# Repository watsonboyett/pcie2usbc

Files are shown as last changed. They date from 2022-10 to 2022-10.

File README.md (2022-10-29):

# PCIe to USB-C Adaptoid

A PCIe to USB-C adapter board -- plugs into a PCIe 1x card slot to breakout the data and clock lanes to a USB-C connector. 
Includes AC coupling caps and jumper resistors to aid in debugging/hacking.
Tested up to PCIe Gen 2 at 5.0 Gbps (though threre's plenty of room for improving the signal integrity).

### Schematic

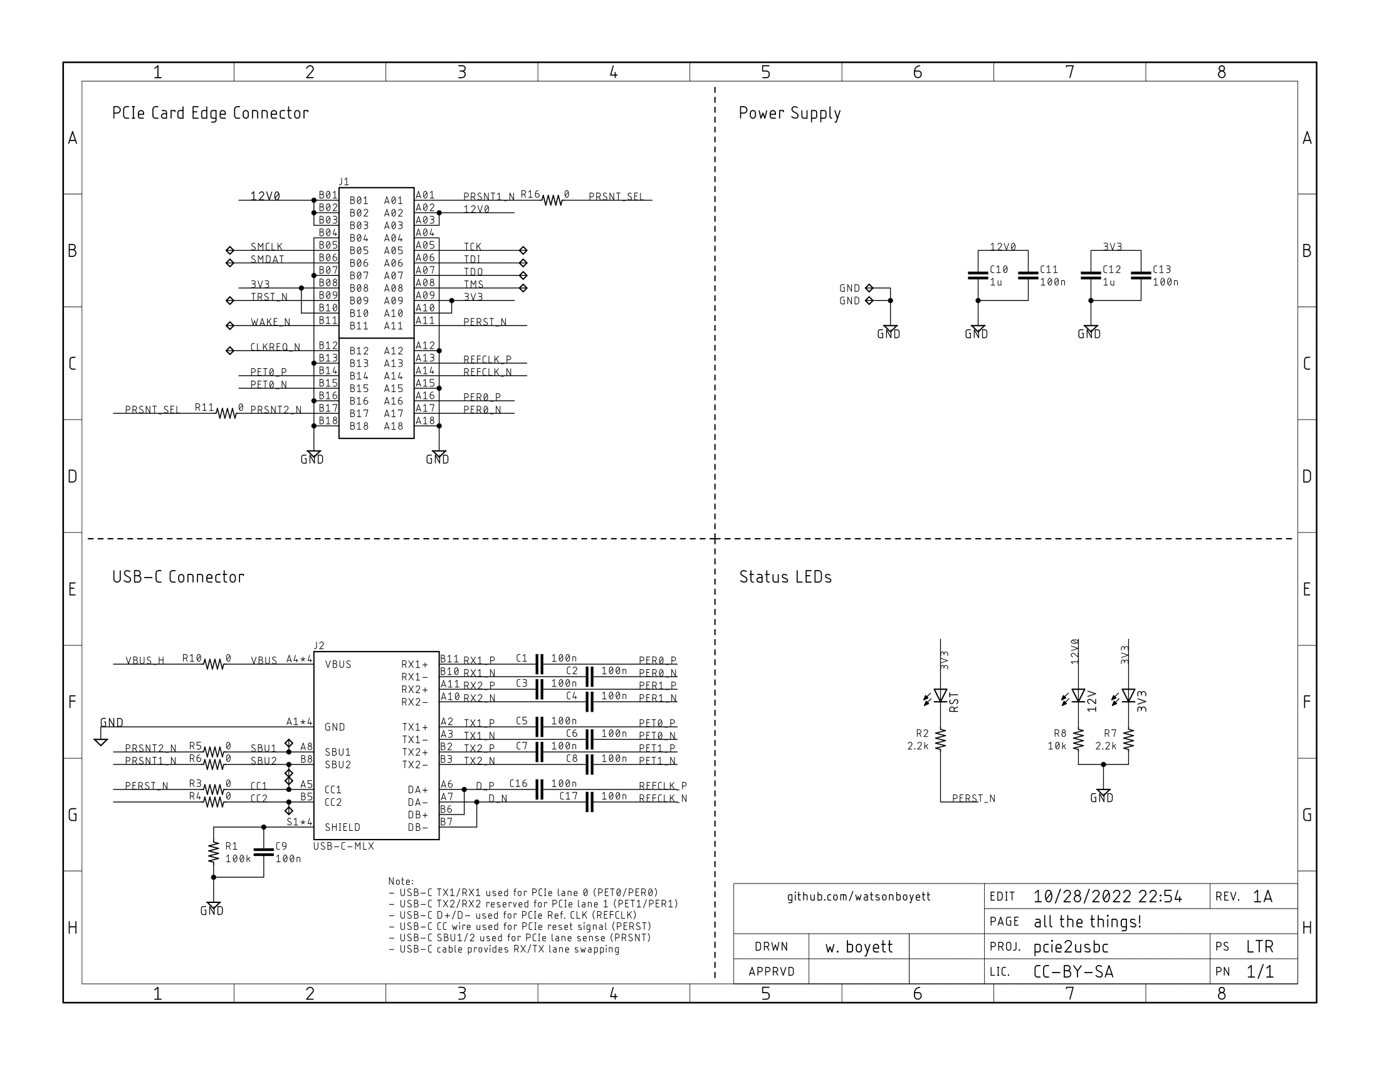
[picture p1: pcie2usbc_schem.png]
Schematic


### PCB Bottom Side

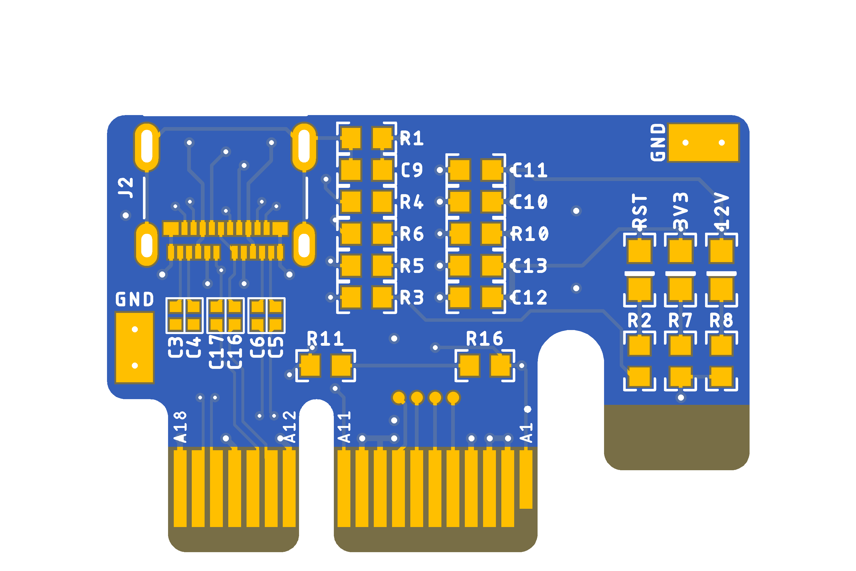
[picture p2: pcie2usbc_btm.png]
PCB Bottom Side


### PCB Top Side

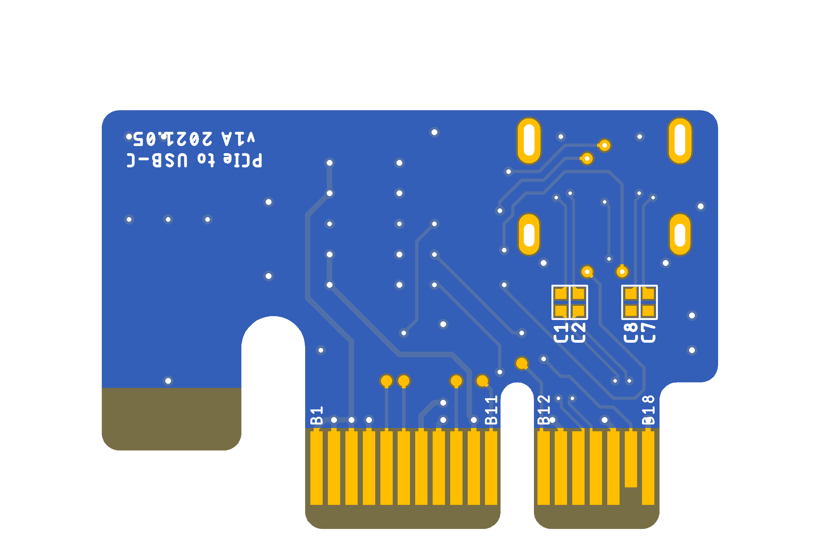
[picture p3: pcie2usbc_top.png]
PCB Top Side


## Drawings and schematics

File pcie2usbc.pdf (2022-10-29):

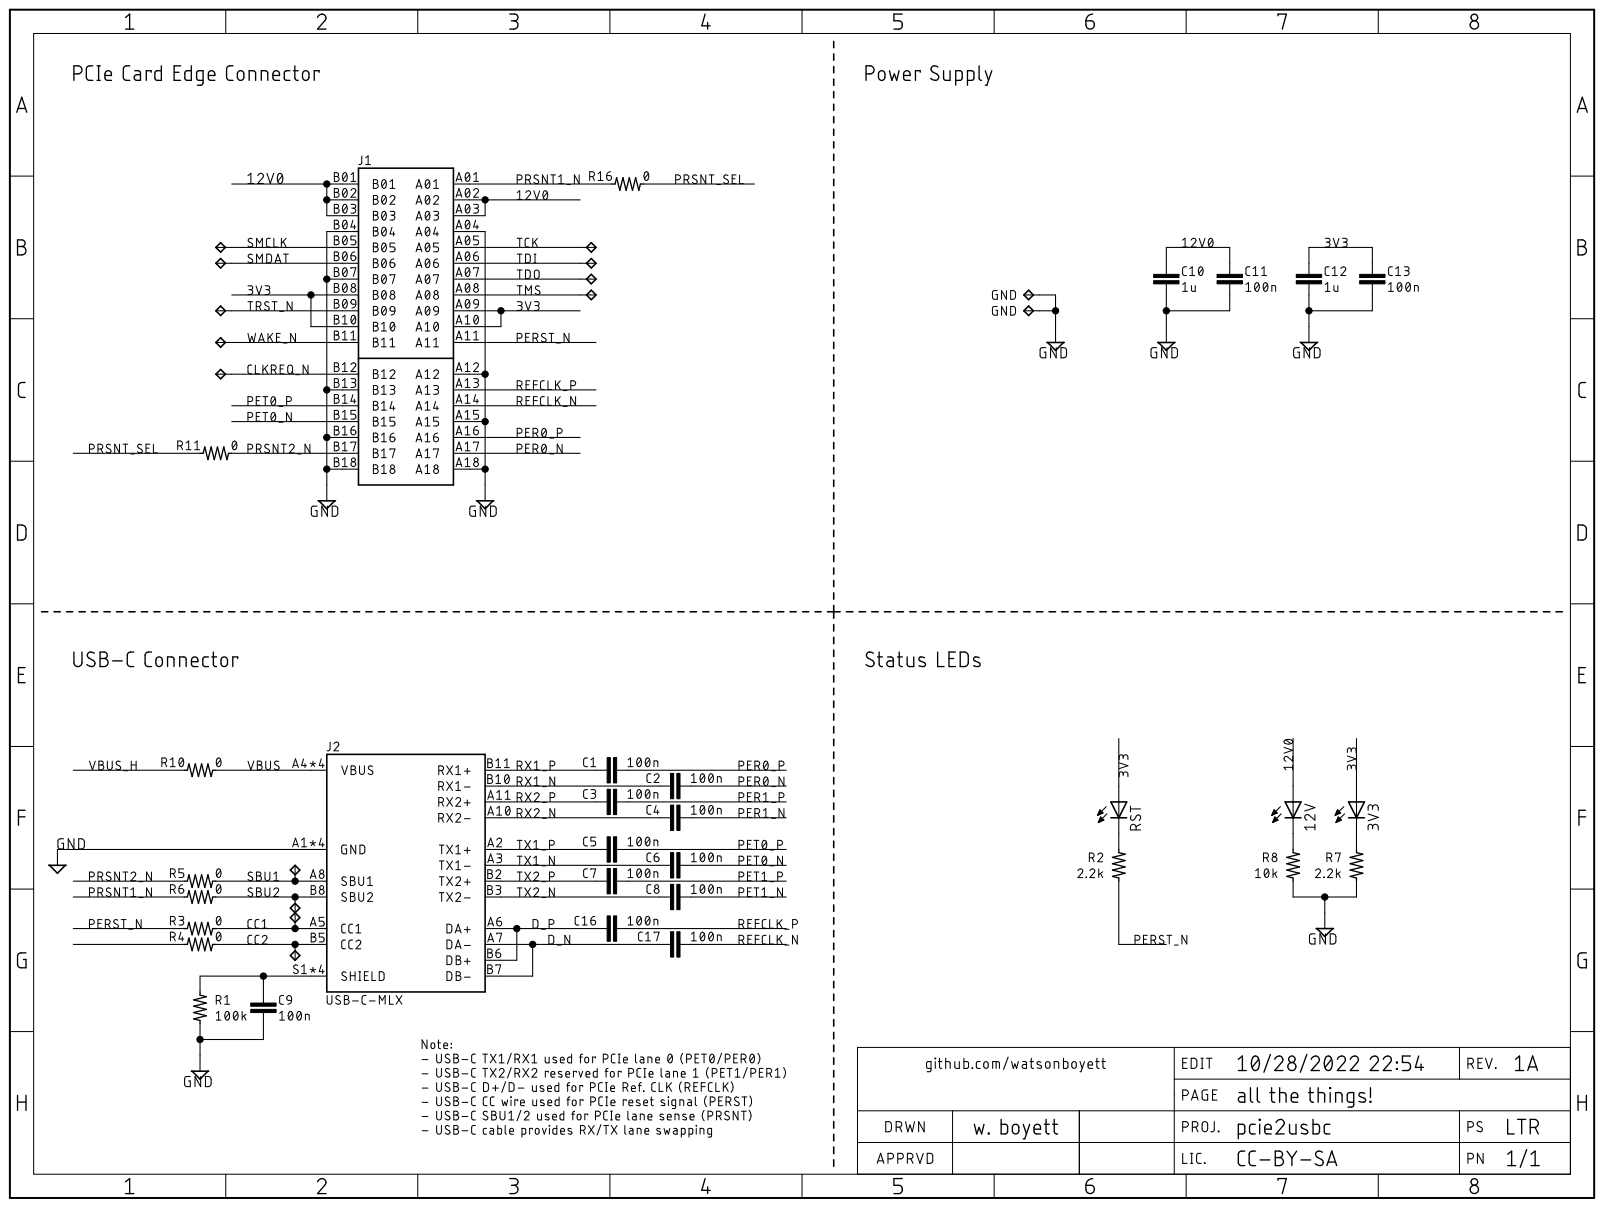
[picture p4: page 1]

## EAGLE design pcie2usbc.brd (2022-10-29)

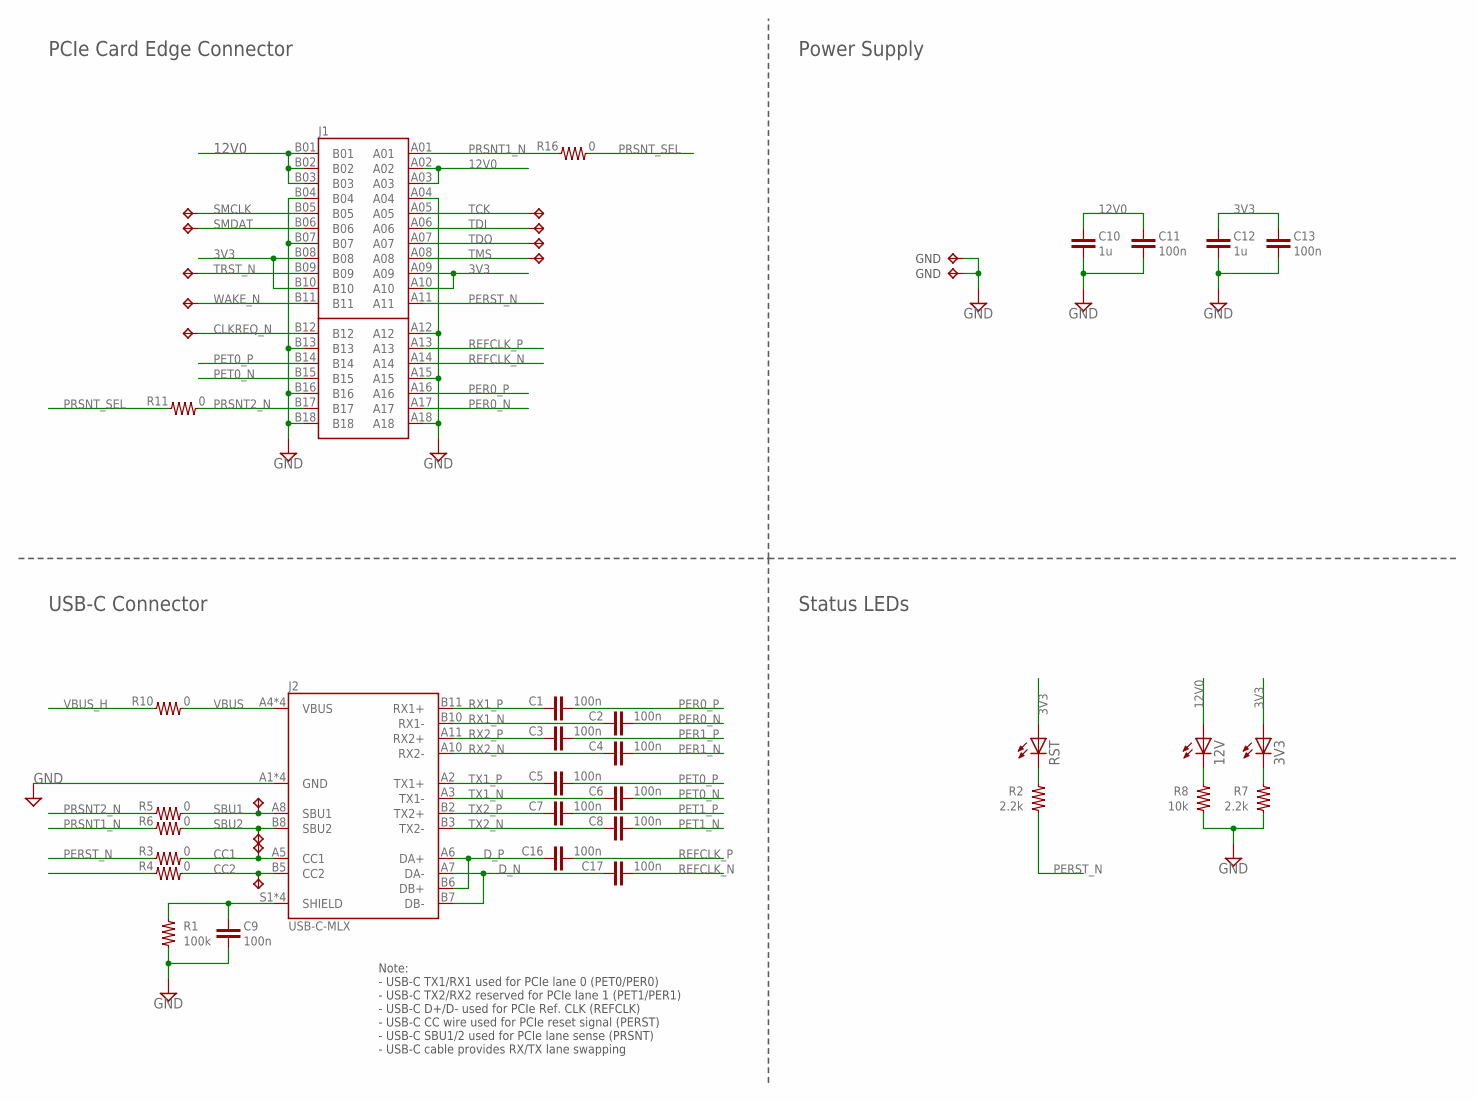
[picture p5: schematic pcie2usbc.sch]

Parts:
3V3, 12V: LEDSML0805; SML0805
C1, C2, C3, C4, C5, C6, C7, C8, C16, C17: 100n; C0402
C9, C11, C13: 100n; C0603K; MPN CC0603KRX7R8BB104
C10, C12: 1u; C0603K; MPN CC0603KRX7R8BB104
J1: PCIE-036-02-X-D-EMS2; SAMTEC_PCIE-036-02-X-D-EMS2
J2: USB-C-MLX; MOLEX_105450-0101
R1: 100k; R0603; MPN RC0603FR-07100KL
R2, R7: 2.2k; R0603
R3, R4, R5, R6, R10, R11, R16: 0; R0603
R8: 10k; R0603
RST: LEDSML0805; SML0805
TP1, TP2, TP3, TP4, TP5, TP6, TP7, TP8, TP9, TP11, TP12, TP16, TP21: TPB0,635; B0,635
TP10, TP13: TPTP38X20; TP38X20

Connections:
3V3: 3V3.A, C12.1, C13.1, J1.A09, J1.A10, J1.B08, J1.B10, RST.A
12V0: 12V.A, C10.1, C11.1, J1.A02, J1.A03, J1.B01, J1.B02, J1.B03
CC1: J2.A5 (CC1), R3.2, TP21.TP
CC2: J2.B5 (CC2), R4.1, TP16.TP
CLKREQ_N: J1.B12, TP9.TP
D_N: C17.1, J2.A7 (DA-), J2.B7 (DB-)
D_P: C16.1, J2.A6 (DA+), J2.B6 (DB+)
GND: C9.2, C10.2, C11.2, C12.2, C13.2, J1.A04, J1.A12, J1.A15, J1.A18, J1.B04, J1.B07, J1.B13, J1.B16, J1.B18, J2.A1 (GND), J2.A12 (GND), J2.B1 (GND), J2.B12 (GND), R1.1, R7.1, R8.1, TP10.TP, TP13.TP
unnamed: 12V.C, R8.2
unnamed: 3V3.C, R7.2
unnamed: R2.2, RST.C
PER0_N: C2.2, J1.A17
PER0_P: C1.2, J1.A16
PER1_N: C4.2
PER1_P: C3.2
PERST_N: J1.A11, R2.1, R3.1
PET0_N: C6.2, J1.B15
PET0_P: C5.2, J1.B14
PET1_N: C8.2
PET1_P: C7.2
PRSNT1_N: J1.A01, R6.1, R16.1
PRSNT2_N: J1.B17, R5.1, R11.2
PRSNT_SEL: R11.1, R16.2
REFCLK_N: C17.2, J1.A14
REFCLK_P: C16.2, J1.A13
RX1_N: C2.1, J2.B10 (RX1-)
RX1_P: C1.1, J2.B11 (RX1+)
RX2_N: C4.1, J2.A10 (RX2-)
RX2_P: C3.1, J2.A11 (RX2+)
SBU1: J2.A8 (SBU1), R5.2, TP11.TP
SBU2: J2.B8 (SBU2), R6.2, TP12.TP
SMCLK: J1.B05, TP5.TP
SMDAT: J1.B06, TP6.TP
TCK: J1.A05, TP1.TP
TDI: J1.A06, TP2.TP
TDO: J1.A07, TP3.TP
TMS: J1.A08, TP4.TP
TRST_N: J1.B09, TP7.TP
TX1_N: C6.1, J2.A3 (TX1-)
TX1_P: C5.1, J2.A2 (TX1+)
TX2_N: C8.1, J2.B3 (TX2-)
TX2_P: C7.1, J2.B2 (TX2+)
USB_SHLD1: C9.1, J2.S1 (SHIELD), J2.S2 (SHIELD), J2.S3 (SHIELD), J2.S4 (SHIELD), R1.2
VBUS: J2.A4 (VBUS), J2.A9 (VBUS), J2.B4 (VBUS), J2.B9 (VBUS), R10.2
VBUS_H: R10.1
WAKE_N: J1.B11, TP8.TP

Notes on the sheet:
PCIe Card Edge Connector
USB-C Connector
Power Supply
Note: - USB-C TX1/RX1 used for PCIe lane 0 (PET0/PER0) - USB-C TX2/RX2 reserved for PCIe lane 1 (PET1/PER1) - USB-C D+/D- used for PCIe Ref. CLK (REFCLK) - USB-C CC wire used for PCIe reset signal (PERST) - USB-C SBU1/2 used for PCIe lane sense (PRSNT) - USB-C cable provides RX/TX lane swapping
Status LEDs

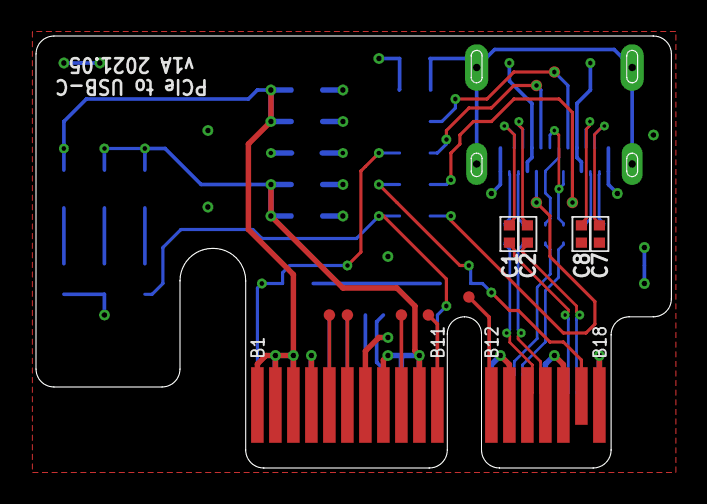
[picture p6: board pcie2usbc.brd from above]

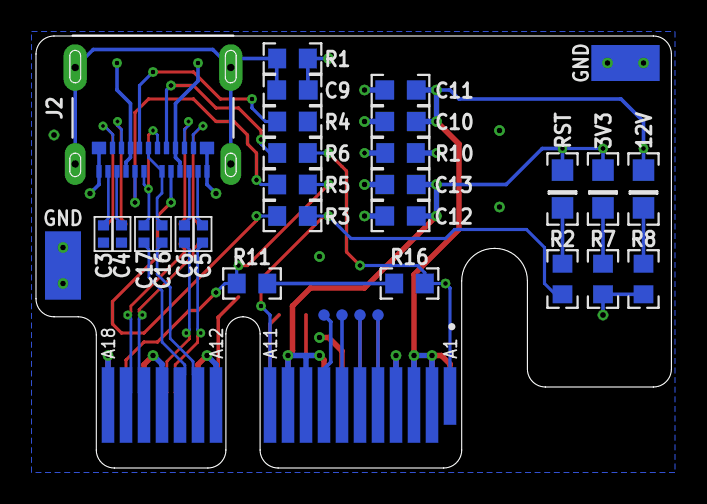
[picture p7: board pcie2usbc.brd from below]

Board: 4 copper layers, 35.3 x 24.0 mm, 46 parts (33 on the bottom side), 41 nets.

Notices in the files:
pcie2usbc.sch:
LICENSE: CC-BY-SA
